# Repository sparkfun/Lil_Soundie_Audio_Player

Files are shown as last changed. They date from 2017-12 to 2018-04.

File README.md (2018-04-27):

SparkFun Little Soundie Audio Player
========================================

Little Soundie Audio Player

[*SparkFun Little Soundie (14006)*](https://www.sparkfun.com/products/14006)

The Little Soundie Audio Player is a breakout board for the VS1000D, an audio decoder capable of playing OGG and WAV type audio files. 
The Little Soundie makes adding sound effects to your project, prop, or costume easily with the built-in USB mass storage for your audio file and simple methods of triggering audio playback.  

Repository Contents
-------------------

* **/Firmware** - VLSI - VS1000D Firmware
* **/Hardware** - Eagle design files (.brd, .sch)
* **/Production** - Production panel files (.brd)
* **/Software** - An easy to use Arduino Template in case you want to hook up your Little Soundie to a Redboard or any board programmed with Arduino.

Documentation
--------------
* **[Hookup Guide](https://learn.sparkfun.com/tutorials/little-soundie-audio-player-hookup-guide)** - Basic hookup guide for the Little Soundie Audio Player.
* **[SparkFun Fritzing repo](https://github.com/sparkfun/Fritzing_Parts)** - Fritzing diagrams for SparkFun products. 

License Information
-------------------

This product is _**open source**_! 

Please review the LICENSE.md file for license information. 

If you have any questions or concerns on licensing, please contact techsupport@sparkfun.com.

Distributed as-is; no warranty is given.

- Your friends at SparkFun.

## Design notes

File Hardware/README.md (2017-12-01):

SparkFun <PRODUCT NAME> Design Files
=====================================

The .sch and .brd files hare are Eagle CAD schematic and PCB design files from SparkFun Electronics.
A freeware version of Eagle can be found [here](http://www.cadsoftusa.com/download-eagle/freeware/).

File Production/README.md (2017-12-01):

SparkFun <PRODUCT NAME> Production Files
=========================================

These are the production files SparkFun uses for printing PCBs.

License Information
-------------------
This product is open source! 

The hardware is released under [Creative Commons ShareAlike 4.0 International](https://creativecommons.org/licenses/by-sa/4.0/).

Please use, reuse, and modify these files as you see fit. Please maintain attribution to SparkFun Electronics and release anything derivative under the same license.

Distributed as-is; no warranty is given.

- Your friends at SparkFun.

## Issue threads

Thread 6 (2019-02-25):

Lil_Soundie_Audio_Player

sidh15, 2019-02-25:
I want to make Lil_Soundie_Audio_Player on a very small board size. Is it possible to make same kind of functionality on the possible smaller size with component?
If yes, what programming are required on the board, if I am buying components separately?                                                                                                                                                                                         I am thinking to place this IC LE25U40CMD from ON semiconductor, will it be compatible for small storage of audio size 150 KB.

bboyho, 2019-04-04:
Hi,

It should be possible to make the board smaller. You should check out the resources provided by the company that manufactures the IC for more information on how to program the IC. There is detailed information available on how to program the chip with the software via USB on the VS1000's product page => [ [http://www.vlsi.fi/en/products/vs1000.html](http://www.vlsi.fi/en/products/vs1000.html) ]. Our hookup guide states that we use the VSIDE software.

As far as the LE25U40CMD IC, this question seems to be out of scope of the product itself and not an issue related with the Lil' Soundie Audio Player. What I can say is that it looks like a SPI serial flash memory similar to the one that is on the Lil' Soundie Audio Player. However, I do not have as much experience with the chip and VS1000D. You should check out the resources linked for more information or check out the [VLSI support forums](http://www.vsdsp-forum.com/phpbb/).

Closed 2019-04-04.

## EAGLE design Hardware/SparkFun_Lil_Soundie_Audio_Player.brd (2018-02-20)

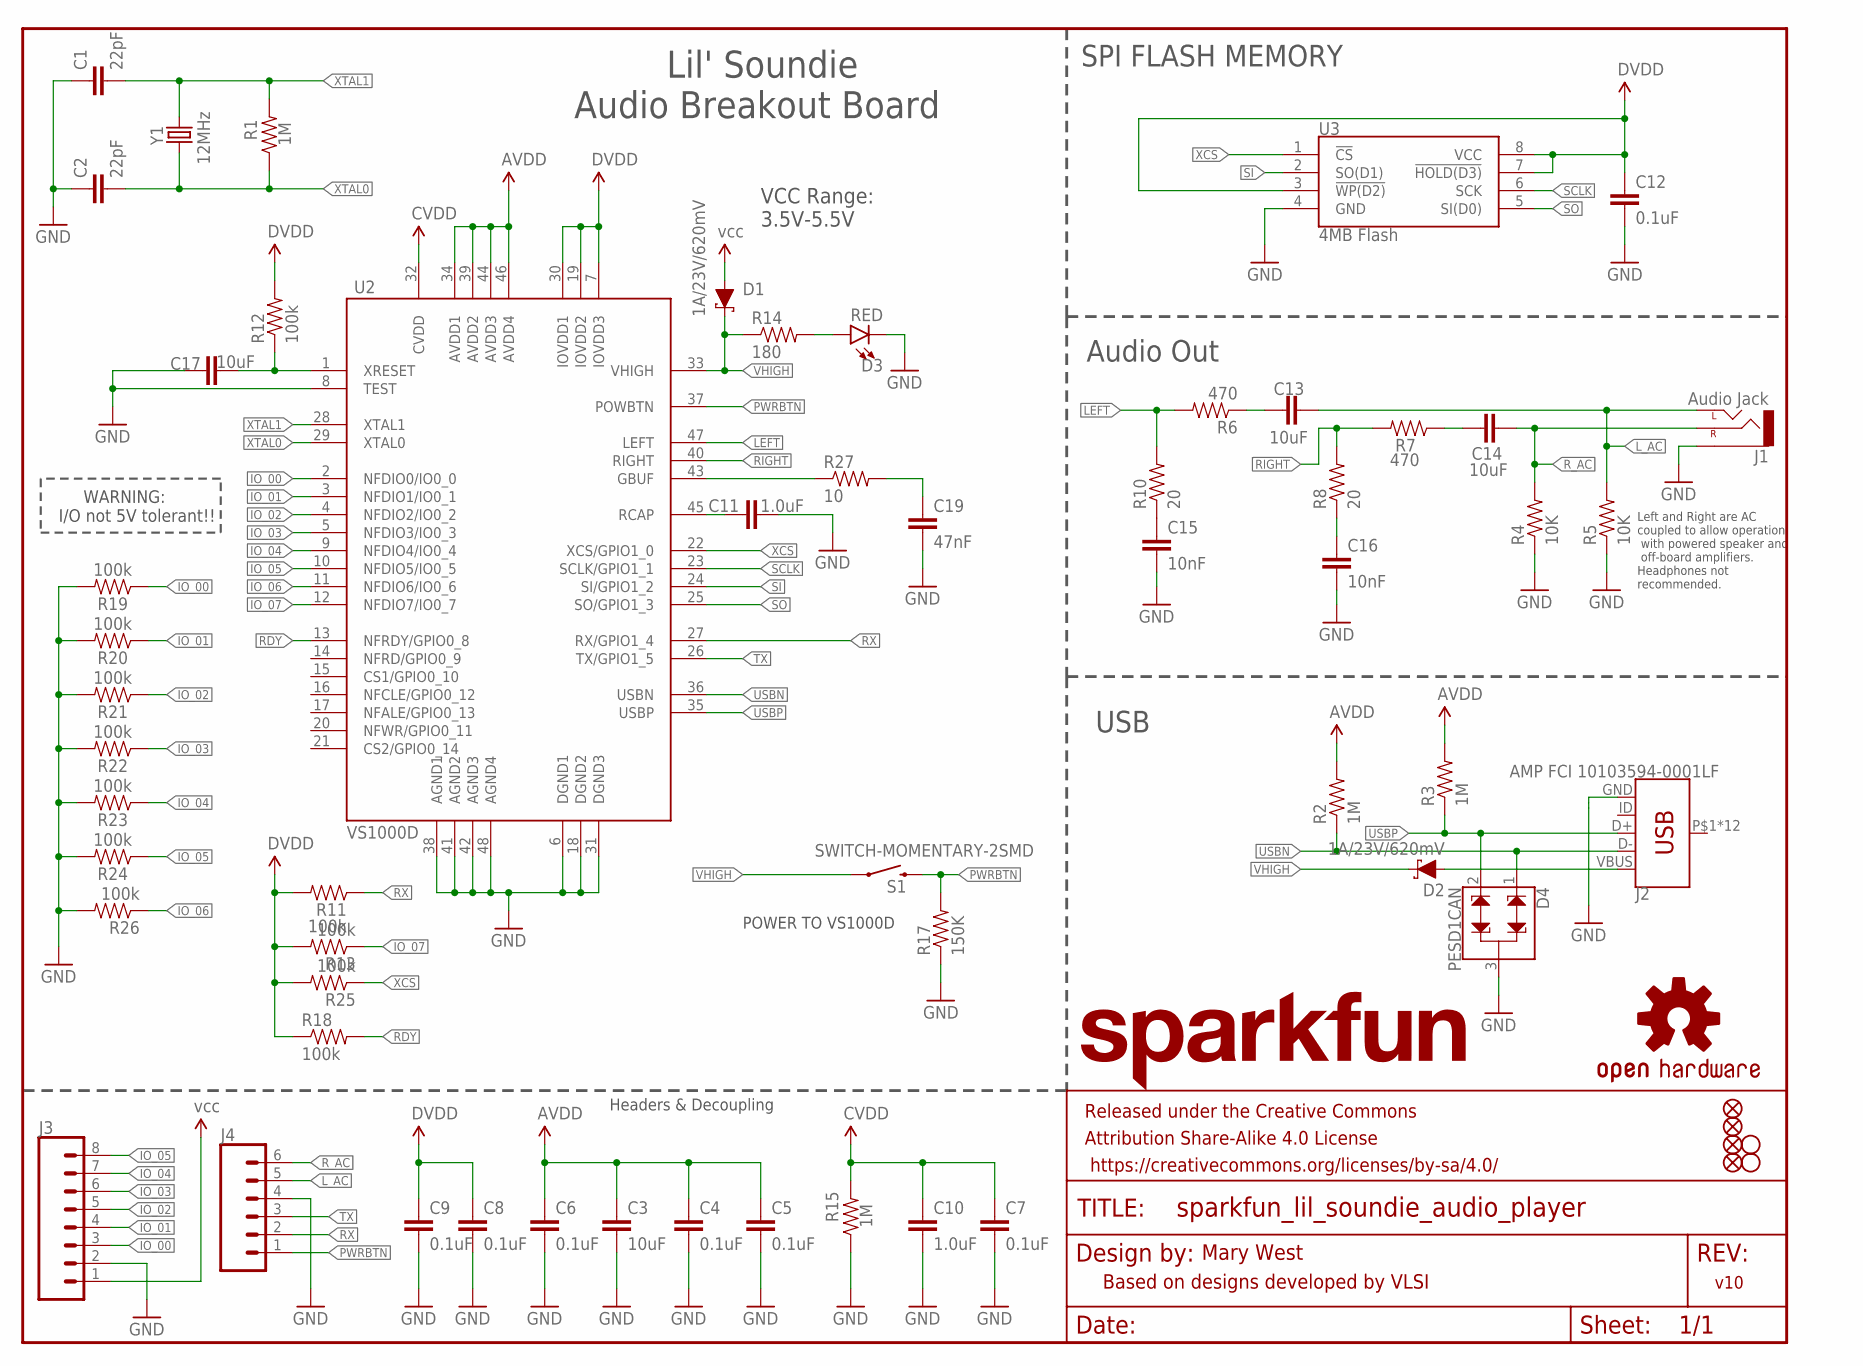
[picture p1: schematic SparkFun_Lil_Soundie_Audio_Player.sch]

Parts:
C1, C2: 22pF; 0603-CAP
C3, C13, C14, C17: 10uF; 0603-CAP
C4, C5, C6, C7, C8, C9, C12: 0.1uF; 0603-CAP
C10, C11: 1.0uF; 0603-CAP
C15, C16: 10nF; 0603-CAP
C19: 47nF; 0603-CAP
D1, D2: 1A/23V/620mV; SOD-323
D3: RED; LED-0603
D4: PESD1CAN; SOT23-3
FD1, FD2, FD3, FD4: FIDUCIALUFIDUCIAL; FIDUCIAL-MICRO
FRAME1: FRAME-LETTER; CREATIVE_COMMONS
H1, H4: STAND-OFFTIGHT; STAND-OFF-TIGHT
J1: Audio Jack; AUDIO-JACK-3.5MM-SMD
J2: AMP FCI 10103594-0001LF; USB-MICROB-PTH
J3: CONN_08"; 1X08
J4: CONN_06SILK_FEMALE_PTH; 1X06
LOGO1: OSHW-LOGOL; OSHW-LOGO-L
LOGO2: SFE_LOGO_NAME.1_INCH; SFE_LOGO_NAME_.1
R1, R2, R3, R15: 1M; 0603-RES
R4, R5: 10K; 0603-RES
R6, R7: 470; 0603-RES
R8, R10: 20; 0603-RES
R11, R12, R13, R18, R25, R26: 100k; 0603-RES
R14: 180; 0603-RES
R17: 150K; 0603-RES
R19, R20, R21, R22, R23, R24: 100k; 0603
R27: 10; 0603-RES
S1: SWITCH-MOMENTARY-2SMD; TACTILE-SWITCH-SMD
U2: VS1000D; LQFP-48
U3: 4MB Flash; SO08
Y1: 12MHz; CRYSTAL-SMD-5X3

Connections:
AVDD: C3.1, C4.1, C5.1, C6.1, R2.2, R3.2, U2.34 (AVDD1), U2.39 (AVDD2), U2.44 (AVDD3), U2.46 (AVDD4)
CVDD: C7.1, C10.1, R15.2, U2.32 (CVDD)
DVDD: C8.1, C9.1, C12.1, R11.2, R12.2, R13.2, R18.1, R25.2, U2.7 (IOVDD3), U2.19 (IOVDD2), U2.30 (IOVDD1), U3.3 (!WP(D2)), U3.7 (!HOLD(D3)), U3.8 (VCC)
GBUF: R27.1, U2.43 (GBUF)
GND: C1.1, C2.1, C3.2, C4.2, C5.2, C6.2, C7.2, C8.2, C9.2, C10.2, C11.2, C12.2, C15.2, C16.2, C17.1, C19.2, D3.C, D4.3, J1.SLEEVE, J2.GND, J3.2, J4.4, R4.1, R5.1, R15.1, R17.1, R19.2, R20.2, R21.2, R22.2, R23.2, R24.2, R26.2, U2.6 (DGND1), U2.8 (TEST), U2.18 (DGND2), U2.31 (DGND3), U2.38 (AGND1), U2.41 (AGND2), U2.42 (AGND3), U2.48 (AGND4), U3.4 (GND)
IO_00: J3.3, R19.1, U2.2 (NFDIO0/IO0_0)
IO_01: J3.4, R20.1, U2.3 (NFDIO1/IO0_1)
IO_02: J3.5, R21.1, U2.4 (NFDIO2/IO0_2)
IO_03: J3.6, R22.1, U2.5 (NFDIO3/IO0_3)
IO_04: J3.7, R23.1, U2.9 (NFDIO4/IO0_4)
IO_05: J3.8, R24.1, U2.10 (NFDIO5/IO0_5)
IO_06: R26.1, U2.11 (NFDIO6/IO0_6)
IO_07: R13.1, U2.12 (NFDIO7/IO0_7)
LEFT: R6.2, R10.2, U2.47 (LEFT)
L_AC: C13.2, J1.TIP (LEFT), J4.5, R5.2
unnamed: C19.1, R27.2
unnamed: C13.1, R6.1
unnamed: C15.1, R10.1
unnamed: C11.1, U2.45 (RCAP)
unnamed: C17.2, R12.1, U2.1 (XRESET)
unnamed: D2.A, J2.VBUS
unnamed: C14.1, R7.1
unnamed: D3.A, R14.2
unnamed: C16.1, R8.1
PWRBTN: J4.1, R17.2, S1.3 (2), U2.37 (POWBTN)
RDY: R18.2, U2.13 (NFRDY/GPIO0_8)
RIGHT: R7.2, R8.2, U2.40 (RIGHT)
RX: J4.2, U2.27 (RX/GPIO1_4)
R_AC: C14.2, J1.RING (RIGHT), J4.6, R4.2
SCLK: U2.23 (SCLK/GPIO1_1), U3.6 (SCK)
SI: U2.24 (SI/GPIO1_2), U3.2 (SO(D1))
SO: U2.25 (SO/GPIO1_3), U3.5 (SI(D0))
TX: J4.3, U2.26 (TX/GPIO1_5)
USBN: D4.1, J2.D-, R2.1, U2.36 (USBN)
USBP: D4.2, J2.D+, R3.1, U2.35 (USBP)
VCC: D1.A, J3.1
VHIGH: D1.C, D2.C, R14.1, S1.1, U2.33 (VHIGH)
XCS: R25.1, U2.22 (XCS/GPIO1_0), U3.1 (!CS)
XTAL0: C2.2, R1.1, U2.29 (XTAL0), Y1.1
XTAL1: C1.2, R1.2, U2.28 (XTAL1), Y1.3 (2)

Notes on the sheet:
Mary West
v10
VCC Range: 3.5V-5.5V
SPI FLASH MEMORY
Headers & Decoupling
POWER TO VS1000D
Left and Right are AC coupled to allow operation with powered speaker and off-board amplifiers. Headphones not recommended.
Based on designs developed by VLSI
WARNING: I/O not 5V tolerant!!
USB
Audio Out
Lil' Soundie Audio Breakout Board

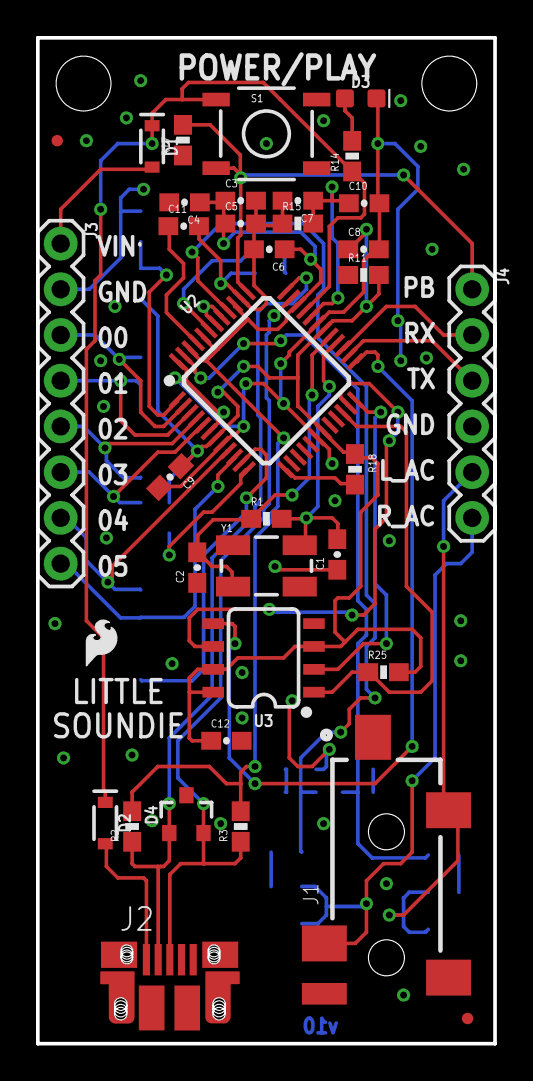
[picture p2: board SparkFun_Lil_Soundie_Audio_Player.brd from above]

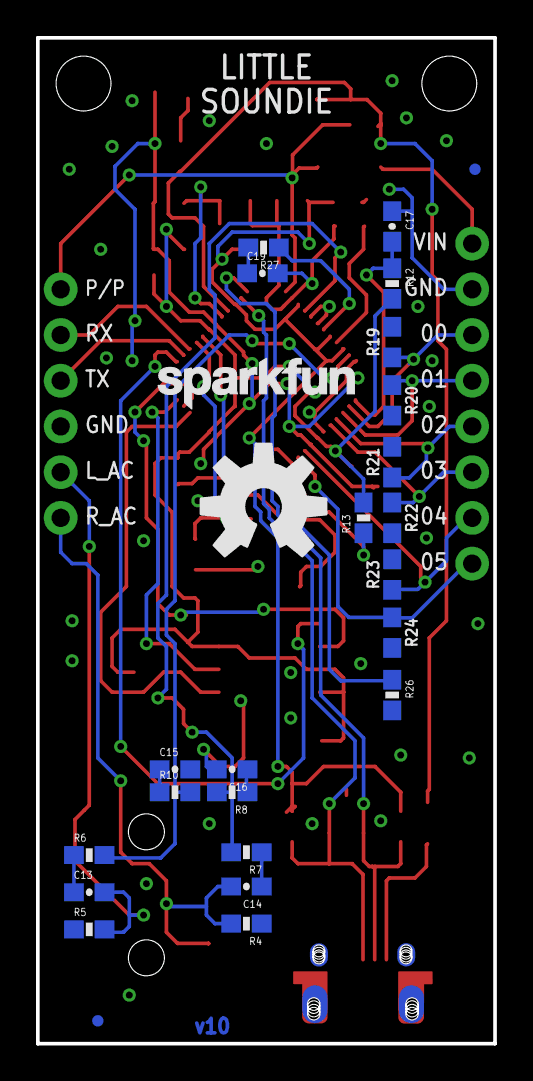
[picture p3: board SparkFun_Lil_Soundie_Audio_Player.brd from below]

Board: 2 copper layers, 25.4 x 55.9 mm, 65 parts (26 on the bottom side), 40 nets.

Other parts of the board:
U$1: SFE_LOGO_FLAME_.1

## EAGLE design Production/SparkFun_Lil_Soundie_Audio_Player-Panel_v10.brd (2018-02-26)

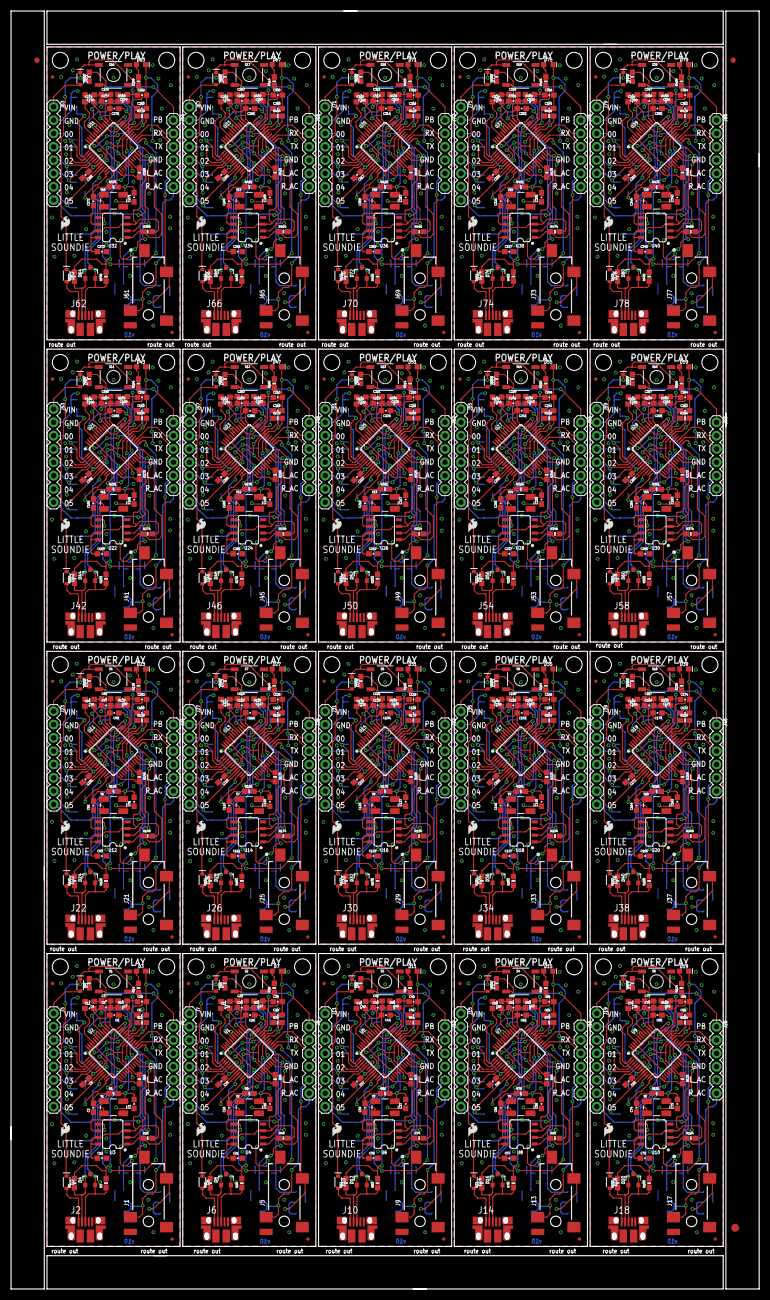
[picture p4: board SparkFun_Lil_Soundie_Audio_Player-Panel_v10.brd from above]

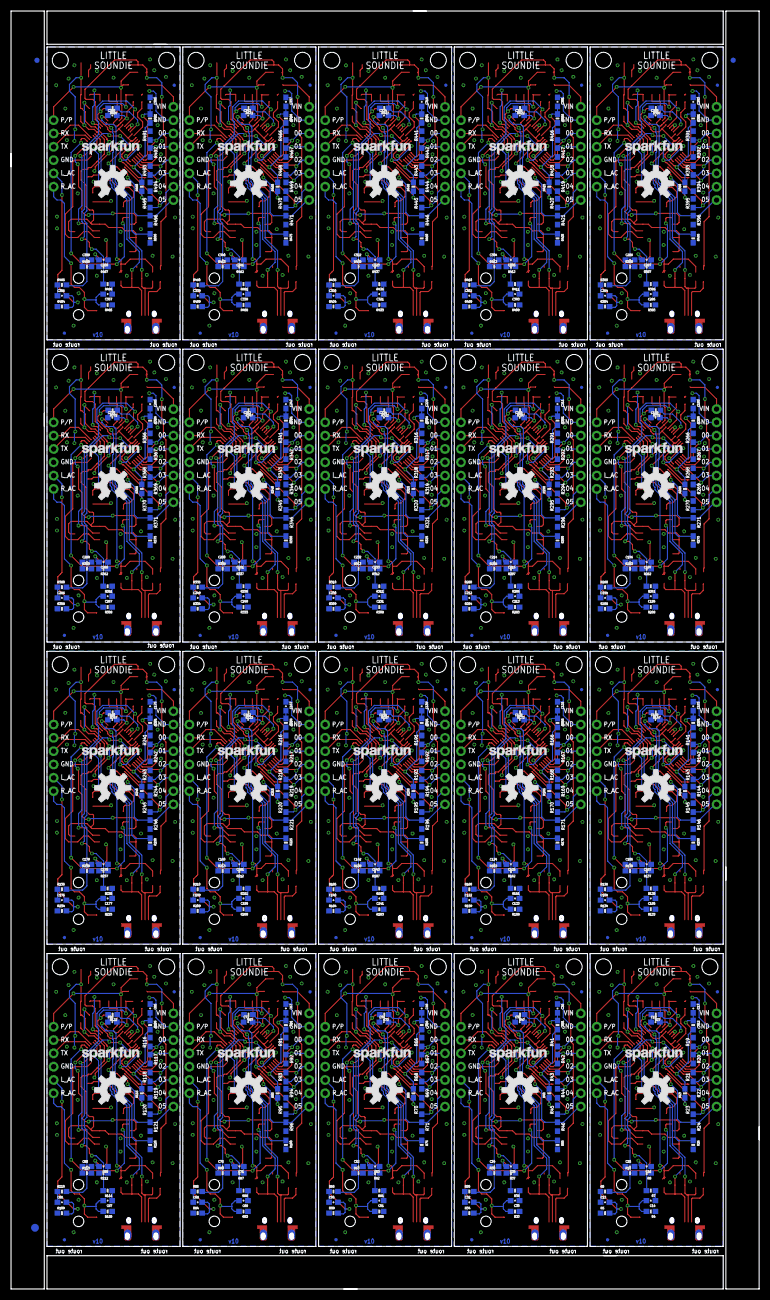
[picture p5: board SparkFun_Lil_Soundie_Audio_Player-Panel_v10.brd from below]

Board: 2 copper layers, 142.7 x 243.8 mm, 1286 parts (523 on the bottom side), 800 nets.

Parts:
C1, C2, C18, C20, C37, C38, C55, C56, C73, C74, C91, C92, C109, C110, C127, C128, C145, C146, C163, C164, C181, C182, C199, C200, C217, C218, C235, C236, C253, C254, C271, C272, C289, C290, C307, C308, C325, C326, C343, C344: 22pF; 0603-CAP
C3, C13, C14, C17, C23, C31, C32, C33, C41, C49, C50, C51, C59, C67, C68, C69, C77, C85, C86, C87, C95, C103, C104, C105, C113, C121, C122, C123, C131, C139, C140, C141, C149, C157, C158, C159, C167, C175, C176, C177, C185, C193, C194, C195, C203, C211, C212, C213, C221, C229, C230, C231, C239, C247, C248, C249, C257, C265, C266, C267, C275, C283, C284, C285, C293, C301, C302, C303, C311, C319, C320, C321, C329, C337, C338, C339, C347, C355, C356, C357: 10uF; 0603-CAP
C4, C5, C6, C7, C8, C9, C12, C21, C24, C25, C26, C27, C28, C29, C39, C42, C43, C44, C45, C46, C47, C57, C60, C61, C62, C63, C64, C65, C75, C78, C79, C80, C81, C82, C83, C93, C96, C97, C98, C99, C100, C101, C111, C114, C115, C116, C117, C118, C119, C129, C132, C133, C134, C135, C136, C137, C147, C150, C151, C152, C153, C154, C155, C165, C168, C169, C170, C171, C172, C173, C183, C186, C187, C188, C189, C190, C191, C201, C204, C205, C206, C207, C208, C209, C219, C222, C223, C224, C225, C226, C227, C237, C240, C241, C242, C243, C244, C245, C255, C258, C259, C260, C261, C262, C263, C273, C276, C277, C278, C279, C280, C281, C291, C294, C295, C296, C297, C298, C299, C309, C312, C313, C314, C315, C316, C317, C327, C330, C331, C332, C333, C334, C335, C345, C348, C349, C350, C351, C352, C353: 0.1uF; 0603-CAP
C10, C11, C22, C30, C40, C48, C58, C66, C76, C84, C94, C102, C112, C120, C130, C138, C148, C156, C166, C174, C184, C192, C202, C210, C220, C228, C238, C246, C256, C264, C274, C282, C292, C300, C310, C318, C328, C336, C346, C354: 1.0uF; 0603-CAP
C15, C16, C34, C35, C52, C53, C70, C71, C88, C89, C106, C107, C124, C125, C142, C143, C160, C161, C178, C179, C196, C197, C214, C215, C232, C233, C250, C251, C268, C269, C286, C287, C304, C305, C322, C323, C340, C341, C358, C359: 10nF; 0603-CAP
C19, C36, C54, C72, C90, C108, C126, C144, C162, C180, C198, C216, C234, C252, C270, C288, C306, C324, C342, C360: 47nF; 0603-CAP
D1, D2, D5, D6, D9, D10, D13, D14, D17, D18, D21, D22, D25, D26, D29, D30, D33, D34, D37, D38, D41, D42, D45, D46, D49, D50, D53, D54, D57, D58, D61, D62, D65, D66, D69, D70, D73, D74, D77, D78: 1A/23V/620mV; SOD-323
D3, D7, D11, D15, D19, D23, D27, D31, D35, D39, D43, D47, D51, D55, D59, D63, D67, D71, D75, D79: RED; LED-0603
D4, D8, D12, D16, D20, D24, D28, D32, D36, D40, D44, D48, D52, D56, D60, D64, D68, D72, D76, D80: PESD1CAN; SOT23-3
E$1, E$2, E$6, E$7: FIDUCIAL-1X2
E$3, E$4: FIDUCIAL-1.5X3
FD1, FD2, FD3, FD4, FD5, FD6, FD7, FD8, FD9, FD10, FD11, FD12, FD13, FD14, FD15, FD16, FD17, FD18, FD19, FD20, FD21, FD22, FD23, FD24, FD25, FD26, FD27, FD28, FD29, FD30, FD31, FD32, FD33, FD34, FD35, FD36, FD37, FD38, FD39, FD40, FD41, FD42, FD43, FD44, FD45, FD46, FD47, FD48, FD49, FD50, FD51, FD52, FD53, FD54, FD55, FD56, FD57, FD58, FD59, FD60, FD61, FD62, FD63, FD64, FD65, FD66, FD67, FD68, FD69, FD70, FD71, FD72, FD73, FD74, FD75, FD76, FD77, FD78, FD79, FD80: FIDUCIALUFIDUCIAL; FIDUCIAL-MICRO
H1, H2, H3, H4, H5, H6, H7, H8, H9, H10, H11, H12, H13, H14, H15, H16, H17, H18, H19, H20, H21, H22, H23, H24, H25, H26, H27, H28, H29, H30, H31, H32, H33, H34, H35, H36, H37, H38, H39, H40: STAND-OFFTIGHT; STAND-OFF-TIGHT
J1, J5, J9, J13, J17, J21, J25, J29, J33, J37, J41, J45, J49, J53, J57, J61, J65, J69, J73, J77: Audio Jack; AUDIO-JACK-3.5MM-SMD
J2, J6, J10, J14, J18, J22, J26, J30, J34, J38, J42, J46, J50, J54, J58, J62, J66, J70, J74, J78: AMP FCI 10103594-0001LF; USB-MICROB-PTH
J3, J7, J11, J15, J19, J23, J27, J31, J35, J39, J43, J47, J51, J55, J59, J63, J67, J71, J75, J79: 1X08
J4, J8, J12, J16, J20, J24, J28, J32, J36, J40, J44, J48, J52, J56, J60, J64, J68, J72, J76, J80: 1X06
LOGO1, LOGO3, LOGO5, LOGO7, LOGO9, LOGO11, LOGO13, LOGO15, LOGO17, LOGO19, LOGO21, LOGO23, LOGO25, LOGO27, LOGO29, LOGO31, LOGO33, LOGO35, LOGO37, LOGO39: OSHW-LOGOL; OSHW-LOGO-L
LOGO2, LOGO4, LOGO6, LOGO8, LOGO10, LOGO12, LOGO14, LOGO16, LOGO18, LOGO20, LOGO22, LOGO24, LOGO26, LOGO28, LOGO30, LOGO32, LOGO34, LOGO36, LOGO38, LOGO40: SFE_LOGO_NAME.1_INCH; SFE_LOGO_NAME_.1
R1, R2, R3, R9, R15, R16, R28, R30, R51, R52, R53, R55, R76, R77, R78, R80, R101, R102, R103, R105, R126, R127, R128, R130, R151, R152, R153, R155, R176, R177, R178, R180, R201, R202, R203, R205, R226, R227, R228, R230, R251, R252, R253, R255, R276, R277, R278, R280, R301, R302, R303, R305, R326, R327, R328, R330, R351, R352, R353, R355, R376, R377, R378, R380, R401, R402, R403, R405, R426, R427, R428, R430, R451, R452, R453, R455, R476, R477, R478, R480: 1M; 0603-RES
R4, R5, R33, R34, R58, R59, R83, R84, R108, R109, R133, R134, R158, R159, R183, R184, R208, R209, R233, R234, R258, R259, R283, R284, R308, R309, R333, R334, R358, R359, R383, R384, R408, R409, R433, R434, R458, R459, R483, R484: 10K; 0603-RES
R6, R7, R35, R36, R60, R61, R85, R86, R110, R111, R135, R136, R160, R161, R185, R186, R210, R211, R235, R236, R260, R261, R285, R286, R310, R311, R335, R336, R360, R361, R385, R386, R410, R411, R435, R436, R460, R461, R485, R486: 470; 0603-RES
R8, R10, R37, R38, R62, R63, R87, R88, R112, R113, R137, R138, R162, R163, R187, R188, R212, R213, R237, R238, R262, R263, R287, R288, R312, R313, R337, R338, R362, R363, R387, R388, R412, R413, R437, R438, R462, R463, R487, R488: 20; 0603-RES
R11, R12, R13, R18, R25, R26, R29, R31, R40, R48, R49, R50, R54, R56, R65, R73, R74, R75, R79, R81, R90, R98, R99, R100, R104, R106, R115, R123, R124, R125, R129, R131, R140, R148, R149, R150, R154, R156, R165, R173, R174, R175, R179, R181, R190, R198, R199, R200, R204, R206, R215, R223, R224, R225, R229, R231, R240, R248, R249, R250, R254, R256, R265, R273, R274, R275, R279, R281, R290, R298, R299, R300, R304, R306, R315, R323, R324, R325, R329, R331, R340, R348, R349, R350, R354, R356, R365, R373, R374, R375, R379, R381, R390, R398, R399, R400, R404, R406, R415, R423, R424, R425, R429, R431, R440, R448, R449, R450, R454, R456, R465, R473, R474, R475, R479, R481, R490, R498, R499, R500: 100k; 0603-RES
R14, R39, R64, R89, R114, R139, R164, R189, R214, R239, R264, R289, R314, R339, R364, R389, R414, R439, R464, R489: 180; 0603-RES
R17, R32, R57, R82, R107, R132, R157, R182, R207, R232, R257, R282, R307, R332, R357, R382, R407, R432, R457, R482: 150K; 0603-RES
R19, R20, R21, R22, R23, R24, R41, R42, R43, R44, R45, R46, R66, R67, R68, R69, R70, R71, R91, R92, R93, R94, R95, R96, R116, R117, R118, R119, R120, R121, R141, R142, R143, R144, R145, R146, R166, R167, R168, R169, R170, R171, R191, R192, R193, R194, R195, R196, R216, R217, R218, R219, R220, R221, R241, R242, R243, R244, R245, R246, R266, R267, R268, R269, R270, R271, R291, R292, R293, R294, R295, R296, R316, R317, R318, R319, R320, R321, R341, R342, R343, R344, R345, R346, R366, R367, R368, R369, R370, R371, R391, R392, R393, R394, R395, R396, R416, R417, R418, R419, R420, R421, R441, R442, R443, R444, R445, R446, R466, R467, R468, R469, R470, R471, R491, R492, R493, R494, R495, R496: 100k; 0603
R27, R47, R72, R97, R122, R147, R172, R197, R222, R247, R272, R297, R322, R347, R372, R397, R422, R447, R472, R497: 10; 0603-RES
S1, S2, S3, S4, S5, S6, S7, S8, S9, S10, S11, S12, S13, S14, S15, S16, S17, S18, S19, S20: SWITCH-MOMENTARY-2SMD; TACTILE-SWITCH-SMD
U1, U2, U5, U7, U9, U11, U13, U15, U17, U19, U21, U23, U25, U27, U29, U31, U33, U35, U37, U39: VS1000D; LQFP-48
U3, U4, U6, U8, U10, U12, U14, U16, U18, U20, U22, U24, U26, U28, U30, U32, U34, U36, U38, U40: 4MB Flash; SO08
U$1, U$2, U$3, U$4, U$5, U$6, U$7, U$8, U$9, U$10, U$11, U$12, U$13, U$14, U$15, U$16, U$17, U$18, U$19, U$20: SFE_LOGO_FLAME_.1
Y1, Y2, Y3, Y4, Y5, Y6, Y7, Y8, Y9, Y10, Y11, Y12, Y13, Y14, Y15, Y16, Y17, Y18, Y19, Y20: 12MHz; CRYSTAL-SMD-5X3

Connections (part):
AVDD: C3.1, C4.1, C5.1, C6.1, R2.2, R3.2, U2.34, U2.39, U2.44, U2.46
AVDD1: C23.1, C24.1, C25.1, C26.1, R16.2, R28.2, U1.34, U1.39, U1.44, U1.46
AVDD2: C41.1, C42.1, C43.1, C44.1, R52.2, R53.2, U5.34, U5.39, U5.44, U5.46
AVDD3: C59.1, C60.1, C61.1, C62.1, R77.2, R78.2, U7.34, U7.39, U7.44, U7.46
AVDD4: C77.1, C78.1, C79.1, C80.1, R102.2, R103.2, U9.34, U9.39, U9.44, U9.46
AVDD5: C95.1, C96.1, C97.1, C98.1, R127.2, R128.2, U11.34, U11.39, U11.44, U11.46
AVDD6: C113.1, C114.1, C115.1, C116.1, R152.2, R153.2, U13.34, U13.39, U13.44, U13.46
AVDD7: C131.1, C132.1, C133.1, C134.1, R177.2, R178.2, U15.34, U15.39, U15.44, U15.46
AVDD8: C149.1, C150.1, C151.1, C152.1, R202.2, R203.2, U17.34, U17.39, U17.44, U17.46
AVDD9: C167.1, C168.1, C169.1, C170.1, R227.2, R228.2, U19.34, U19.39, U19.44, U19.46
AVDD10: C185.1, C186.1, C187.1, C188.1, R252.2, R253.2, U21.34, U21.39, U21.44, U21.46
AVDD11: C203.1, C204.1, C205.1, C206.1, R277.2, R278.2, U23.34, U23.39, U23.44, U23.46
AVDD12: C221.1, C222.1, C223.1, C224.1, R302.2, R303.2, U25.34, U25.39, U25.44, U25.46
AVDD13: C239.1, C240.1, C241.1, C242.1, R327.2, R328.2, U27.34, U27.39, U27.44, U27.46
AVDD14: C257.1, C258.1, C259.1, C260.1, R352.2, R353.2, U29.34, U29.39, U29.44, U29.46
AVDD15: C275.1, C276.1, C277.1, C278.1, R377.2, R378.2, U31.34, U31.39, U31.44, U31.46
AVDD16: C293.1, C294.1, C295.1, C296.1, R402.2, R403.2, U33.34, U33.39, U33.44, U33.46
AVDD17: C311.1, C312.1, C313.1, C314.1, R427.2, R428.2, U35.34, U35.39, U35.44, U35.46
AVDD18: C329.1, C330.1, C331.1, C332.1, R452.2, R453.2, U37.34, U37.39, U37.44, U37.46
AVDD19: C347.1, C348.1, C349.1, C350.1, R477.2, R478.2, U39.34, U39.39, U39.44, U39.46
CVDD: C7.1, C10.1, R15.2, U2.32
CVDD1: C27.1, C30.1, R30.2, U1.32
CVDD2: C45.1, C48.1, R55.2, U5.32
CVDD3: C63.1, C66.1, R80.2, U7.32
CVDD4: C81.1, C84.1, R105.2, U9.32
CVDD5: C99.1, C102.1, R130.2, U11.32
CVDD6: C117.1, C120.1, R155.2, U13.32
CVDD7: C135.1, C138.1, R180.2, U15.32
CVDD8: C153.1, C156.1, R205.2, U17.32
CVDD9: C171.1, C174.1, R230.2, U19.32
CVDD10: C189.1, C192.1, R255.2, U21.32
CVDD11: C207.1, C210.1, R280.2, U23.32
CVDD12: C225.1, C228.1, R305.2, U25.32
CVDD13: C243.1, C246.1, R330.2, U27.32
CVDD14: C261.1, C264.1, R355.2, U29.32
CVDD15: C279.1, C282.1, R380.2, U31.32
CVDD16: C297.1, C300.1, R405.2, U33.32
CVDD17: C315.1, C318.1, R430.2, U35.32
CVDD18: C333.1, C336.1, R455.2, U37.32
CVDD19: C351.1, C354.1, R480.2, U39.32
DVDD: C8.1, C9.1, C12.1, R11.2, R12.2, R13.2, R18.1, R25.2, U2.7, U2.19, U2.30, U3.3, U3.7, U3.8
DVDD1: C21.1, C28.1, C29.1, R29.2, R31.2, R40.2, R48.1, R49.2, U1.7, U1.19, U1.30, U4.3, U4.7, U4.8
DVDD2: C39.1, C46.1, C47.1, R54.2, R56.2, R65.2, R73.1, R74.2, U5.7, U5.19, U5.30, U6.3, U6.7, U6.8
DVDD3: C57.1, C64.1, C65.1, R79.2, R81.2, R90.2, R98.1, R99.2, U7.7, U7.19, U7.30, U8.3, U8.7, U8.8
DVDD4: C75.1, C82.1, C83.1, R104.2, R106.2, R115.2, R123.1, R124.2, U9.7, U9.19, U9.30, U10.3, U10.7, U10.8
DVDD5: C93.1, C100.1, C101.1, R129.2, R131.2, R140.2, R148.1, R149.2, U11.7, U11.19, U11.30, U12.3, U12.7, U12.8
DVDD6: C111.1, C118.1, C119.1, R154.2, R156.2, R165.2, R173.1, R174.2, U13.7, U13.19, U13.30, U14.3, U14.7, U14.8
DVDD7: C129.1, C136.1, C137.1, R179.2, R181.2, R190.2, R198.1, R199.2, U15.7, U15.19, U15.30, U16.3, U16.7, U16.8
DVDD8: C147.1, C154.1, C155.1, R204.2, R206.2, R215.2, R223.1, R224.2, U17.7, U17.19, U17.30, U18.3, U18.7, U18.8
DVDD9: C165.1, C172.1, C173.1, R229.2, R231.2, R240.2, R248.1, R249.2, U19.7, U19.19, U19.30, U20.3, U20.7, U20.8
DVDD10: C183.1, C190.1, C191.1, R254.2, R256.2, R265.2, R273.1, R274.2, U21.7, U21.19, U21.30, U22.3, U22.7, U22.8
DVDD11: C201.1, C208.1, C209.1, R279.2, R281.2, R290.2, R298.1, R299.2, U23.7, U23.19, U23.30, U24.3, U24.7, U24.8
DVDD12: C219.1, C226.1, C227.1, R304.2, R306.2, R315.2, R323.1, R324.2, U25.7, U25.19, U25.30, U26.3, U26.7, U26.8
DVDD13: C237.1, C244.1, C245.1, R329.2, R331.2, R340.2, R348.1, R349.2, U27.7, U27.19, U27.30, U28.3, U28.7, U28.8
DVDD14: C255.1, C262.1, C263.1, R354.2, R356.2, R365.2, R373.1, R374.2, U29.7, U29.19, U29.30, U30.3, U30.7, U30.8
DVDD15: C273.1, C280.1, C281.1, R379.2, R381.2, R390.2, R398.1, R399.2, U31.7, U31.19, U31.30, U32.3, U32.7, U32.8
DVDD16: C291.1, C298.1, C299.1, R404.2, R406.2, R415.2, R423.1, R424.2, U33.7, U33.19, U33.30, U34.3, U34.7, U34.8
DVDD17: C309.1, C316.1, C317.1, R429.2, R431.2, R440.2, R448.1, R449.2, U35.7, U35.19, U35.30, U36.3, U36.7, U36.8
DVDD18: C327.1, C334.1, C335.1, R454.2, R456.2, R465.2, R473.1, R474.2, U37.7, U37.19, U37.30, U38.3, U38.7, U38.8
DVDD19: C345.1, C352.1, C353.1, R479.2, R481.2, R490.2, R498.1, R499.2, U39.7, U39.19, U39.30, U40.3, U40.7, U40.8
GBUF: R27.1, U2.43
GBUF1: R47.1, U1.43
GBUF2: R72.1, U5.43
GBUF3: R97.1, U7.43
GBUF4: R122.1, U9.43
GBUF5: R147.1, U11.43
GBUF6: R172.1, U13.43
GBUF7: R197.1, U15.43
GBUF8: R222.1, U17.43
GBUF9: R247.1, U19.43
GBUF10: R272.1, U21.43
GBUF11: R297.1, U23.43
GBUF12: R322.1, U25.43
GBUF13: R347.1, U27.43
GBUF14: R372.1, U29.43
GBUF15: R397.1, U31.43
GBUF16: R422.1, U33.43
GBUF17: R447.1, U35.43
GBUF18: R472.1, U37.43
GBUF19: R497.1, U39.43
GND: C1.1, C2.1, C3.2, C4.2, C5.2, C6.2, C7.2, C8.2, C9.2, C10.2, C11.2, C12.2, C15.2, C16.2, C17.1, C19.2, D3.C, D4.3, J1.SLEEVE, J2.GND, J3.2, J4.4, R4.1, R5.1, R15.1, R17.1, R19.2, R20.2, R21.2, R22.2, R23.2, R24.2, R26.2, U2.6, U2.8, U2.18, U2.31, U2.38, U2.41, U2.42, U2.48, U3.4
GND1: C18.1, C20.1, C21.2, C22.2, C23.2, C24.2, C25.2, C26.2, C27.2, C28.2, C29.2, C30.2, C31.1, C34.2, C35.2, C36.2, D7.C, D8.3, J5.SLEEVE, J6.GND, J7.2, J8.4, R30.1, R32.1, R33.1, R34.1, R41.2, R42.2, R43.2, R44.2, R45.2, R46.2, R50.2, U1.6, U1.8, U1.18, U1.31, U1.38, U1.41, U1.42, U1.48, U4.4
GND2: C37.1, C38.1, C39.2, C40.2, C41.2, C42.2, C43.2, C44.2, C45.2, C46.2, C47.2, C48.2, C49.1, C52.2, C53.2, C54.2, D11.C, D12.3, J9.SLEEVE, J10.GND, J11.2, J12.4, R55.1, R57.1, R58.1, R59.1, R66.2, R67.2, R68.2, R69.2, R70.2, R71.2, R75.2, U5.6, U5.8, U5.18, U5.31, U5.38, U5.41, U5.42, U5.48, U6.4
GND3: C55.1, C56.1, C57.2, C58.2, C59.2, C60.2, C61.2, C62.2, C63.2, C64.2, C65.2, C66.2, C67.1, C70.2, C71.2, C72.2, D15.C, D16.3, J13.SLEEVE, J14.GND, J15.2, J16.4, R80.1, R82.1, R83.1, R84.1, R91.2, R92.2, R93.2, R94.2, R95.2, R96.2, R100.2, U7.6, U7.8, U7.18, U7.31, U7.38, U7.41, U7.42, U7.48, U8.4
GND4: C73.1, C74.1, C75.2, C76.2, C77.2, C78.2, C79.2, C80.2, C81.2, C82.2, C83.2, C84.2, C85.1, C88.2, C89.2, C90.2, D19.C, D20.3, J17.SLEEVE, J18.GND, J19.2, J20.4, R105.1, R107.1, R108.1, R109.1, R116.2, R117.2, R118.2, R119.2, R120.2, R121.2, R125.2, U9.6, U9.8, U9.18, U9.31, U9.38, U9.41, U9.42, U9.48, U10.4
GND5: C91.1, C92.1, C93.2, C94.2, C95.2, C96.2, C97.2, C98.2, C99.2, C100.2, C101.2, C102.2, C103.1, C106.2, C107.2, C108.2, D23.C, D24.3, J21.SLEEVE, J22.GND, J23.2, J24.4, R130.1, R132.1, R133.1, R134.1, R141.2, R142.2, R143.2, R144.2, R145.2, R146.2, R150.2, U11.6, U11.8, U11.18, U11.31, U11.38, U11.41, U11.42, U11.48, U12.4
GND6: C109.1, C110.1, C111.2, C112.2, C113.2, C114.2, C115.2, C116.2, C117.2, C118.2, C119.2, C120.2, C121.1, C124.2, C125.2, C126.2, D27.C, D28.3, J25.SLEEVE, J26.GND, J27.2, J28.4, R155.1, R157.1, R158.1, R159.1, R166.2, R167.2, R168.2, R169.2, R170.2, R171.2, R175.2, U13.6, U13.8, U13.18, U13.31, U13.38, U13.41, U13.42, U13.48, U14.4
GND7: C127.1, C128.1, C129.2, C130.2, C131.2, C132.2, C133.2, C134.2, C135.2, C136.2, C137.2, C138.2, C139.1, C142.2, C143.2, C144.2, D31.C, D32.3, J29.SLEEVE, J30.GND, J31.2, J32.4, R180.1, R182.1, R183.1, R184.1, R191.2, R192.2, R193.2, R194.2, R195.2, R196.2, R200.2, U15.6, U15.8, U15.18, U15.31, U15.38, U15.41, U15.42, U15.48, U16.4
GND8: C145.1, C146.1, C147.2, C148.2, C149.2, C150.2, C151.2, C152.2, C153.2, C154.2, C155.2, C156.2, C157.1, C160.2, C161.2, C162.2, D35.C, D36.3, J33.SLEEVE, J34.GND, J35.2, J36.4, R205.1, R207.1, R208.1, R209.1, R216.2, R217.2, R218.2, R219.2, R220.2, R221.2, R225.2, U17.6, U17.8, U17.18, U17.31, U17.38, U17.41, U17.42, U17.48, U18.4
GND9: C163.1, C164.1, C165.2, C166.2, C167.2, C168.2, C169.2, C170.2, C171.2, C172.2, C173.2, C174.2, C175.1, C178.2, C179.2, C180.2, D39.C, D40.3, J37.SLEEVE, J38.GND, J39.2, J40.4, R230.1, R232.1, R233.1, R234.1, R241.2, R242.2, R243.2, R244.2, R245.2, R246.2, R250.2, U19.6, U19.8, U19.18, U19.31, U19.38, U19.41, U19.42, U19.48, U20.4
GND10: C181.1, C182.1, C183.2, C184.2, C185.2, C186.2, C187.2, C188.2, C189.2, C190.2, C191.2, C192.2, C193.1, C196.2, C197.2, C198.2, D43.C, D44.3, J41.SLEEVE, J42.GND, J43.2, J44.4, R255.1, R257.1, R258.1, R259.1, R266.2, R267.2, R268.2, R269.2, R270.2, R271.2, R275.2, U21.6, U21.8, U21.18, U21.31, U21.38, U21.41, U21.42, U21.48, U22.4
GND11: C199.1, C200.1, C201.2, C202.2, C203.2, C204.2, C205.2, C206.2, C207.2, C208.2, C209.2, C210.2, C211.1, C214.2, C215.2, C216.2, D47.C, D48.3, J45.SLEEVE, J46.GND, J47.2, J48.4, R280.1, R282.1, R283.1, R284.1, R291.2, R292.2, R293.2, R294.2, R295.2, R296.2, R300.2, U23.6, U23.8, U23.18, U23.31, U23.38, U23.41, U23.42, U23.48, U24.4
GND12: C217.1, C218.1, C219.2, C220.2, C221.2, C222.2, C223.2, C224.2, C225.2, C226.2, C227.2, C228.2, C229.1, C232.2, C233.2, C234.2, D51.C, D52.3, J49.SLEEVE, J50.GND, J51.2, J52.4, R305.1, R307.1, R308.1, R309.1, R316.2, R317.2, R318.2, R319.2, R320.2, R321.2, R325.2, U25.6, U25.8, U25.18, U25.31, U25.38, U25.41, U25.42, U25.48, U26.4
GND13: C235.1, C236.1, C237.2, C238.2, C239.2, C240.2, C241.2, C242.2, C243.2, C244.2, C245.2, C246.2, C247.1, C250.2, C251.2, C252.2, D55.C, D56.3, J53.SLEEVE, J54.GND, J55.2, J56.4, R330.1, R332.1, R333.1, R334.1, R341.2, R342.2, R343.2, R344.2, R345.2, R346.2, R350.2, U27.6, U27.8, U27.18, U27.31, U27.38, U27.41, U27.42, U27.48, U28.4
GND14: C253.1, C254.1, C255.2, C256.2, C257.2, C258.2, C259.2, C260.2, C261.2, C262.2, C263.2, C264.2, C265.1, C268.2, C269.2, C270.2, D59.C, D60.3, J57.SLEEVE, J58.GND, J59.2, J60.4, R355.1, R357.1, R358.1, R359.1, R366.2, R367.2, R368.2, R369.2, R370.2, R371.2, R375.2, U29.6, U29.8, U29.18, U29.31, U29.38, U29.41, U29.42, U29.48, U30.4
GND15: C271.1, C272.1, C273.2, C274.2, C275.2, C276.2, C277.2, C278.2, C279.2, C280.2, C281.2, C282.2, C283.1, C286.2, C287.2, C288.2, D63.C, D64.3, J61.SLEEVE, J62.GND, J63.2, J64.4, R380.1, R382.1, R383.1, R384.1, R391.2, R392.2, R393.2, R394.2, R395.2, R396.2, R400.2, U31.6, U31.8, U31.18, U31.31, U31.38, U31.41, U31.42, U31.48, U32.4
GND16: C289.1, C290.1, C291.2, C292.2, C293.2, C294.2, C295.2, C296.2, C297.2, C298.2, C299.2, C300.2, C301.1, C304.2, C305.2, C306.2, D67.C, D68.3, J65.SLEEVE, J66.GND, J67.2, J68.4, R405.1, R407.1, R408.1, R409.1, R416.2, R417.2, R418.2, R419.2, R420.2, R421.2, R425.2, U33.6, U33.8, U33.18, U33.31, U33.38, U33.41, U33.42, U33.48, U34.4
GND17: C307.1, C308.1, C309.2, C310.2, C311.2, C312.2, C313.2, C314.2, C315.2, C316.2, C317.2, C318.2, C319.1, C322.2, C323.2, C324.2, D71.C, D72.3, J69.SLEEVE, J70.GND, J71.2, J72.4, R430.1, R432.1, R433.1, R434.1, R441.2, R442.2, R443.2, R444.2, R445.2, R446.2, R450.2, U35.6, U35.8, U35.18, U35.31, U35.38, U35.41, U35.42, U35.48, U36.4
GND18: C325.1, C326.1, C327.2, C328.2, C329.2, C330.2, C331.2, C332.2, C333.2, C334.2, C335.2, C336.2, C337.1, C340.2, C341.2, C342.2, D75.C, D76.3, J73.SLEEVE, J74.GND, J75.2, J76.4, R455.1, R457.1, R458.1, R459.1, R466.2, R467.2, R468.2, R469.2, R470.2, R471.2, R475.2, U37.6, U37.8, U37.18, U37.31, U37.38, U37.41, U37.42, U37.48, U38.4
GND19: C343.1, C344.1, C345.2, C346.2, C347.2, C348.2, C349.2, C350.2, C351.2, C352.2, C353.2, C354.2, C355.1, C358.2, C359.2, C360.2, D79.C, D80.3, J77.SLEEVE, J78.GND, J79.2, J80.4, R480.1, R482.1, R483.1, R484.1, R491.2, R492.2, R493.2, R494.2, R495.2, R496.2, R500.2, U39.6, U39.8, U39.18, U39.31, U39.38, U39.41, U39.42, U39.48, U40.4
IO_00: J3.3, R19.1, U2.2
IO_01: J3.4, R20.1, U2.3
IO_02: J3.5, R21.1, U2.4
IO_03: J3.6, R22.1, U2.5
IO_04: J3.7, R23.1, U2.9
IO_05: J3.8, R24.1, U2.10
IO_06: R26.1, U2.11
IO_07: R13.1, U2.12
IO_08: J7.8, R46.1, U1.10
IO_09: J7.3, R41.1, U1.2
IO_10: J7.4, R42.1, U1.3
IO_11: J7.6, R44.1, U1.5
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

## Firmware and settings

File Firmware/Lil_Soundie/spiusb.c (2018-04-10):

/// \file spiusb.c Winbond 25X16 SPI flash/USB/Vorbis player demo project
/*

   Copyright 2008 VLSI Solution, Tampere, Finland. Absolutely no warranty.


   S P I   F L A S H   U S B   D R I V E  +  P L A Y E R   E X A M P L E
   ---------------------------------------------------------------------

   This example code uses the 18 kilobytes of mallocAreaY to implement
   a disk read/write cache and work area that is capable of erasing and
   programming an SPI flash chip such as the Winbond 25X16 in 4 kilobyte
   chunks when the VS1000B is connected to USB. Tested with Windows XP.

Note: The SPI flash is quite slow to write to (about the speed of
a floppy disk). Writing small files (a few kilobytes) is fast due
to the cache system. Large files may cause occasional timeouts with
slow flash chips.

Requirements: An SPI flash eeprom with 4 kilobyte erasable blocks.

Tested with VS1000B, Winbond 25X16 and Windows XP Professional.
Measured performance: 1 megabyte file was written in 55 seconds when
the eeprom was blank (no need to erase). When writing over already
written data, writing the same file took 1 minute 35 seconds.

Builds with vskit133 build script (BUILD SPIUSB)
eeprom.img can be then prommed to the eeprom for bootable system.
Then you can use your development board to make a master EEPROM image,
which you can copy to the production units using an eeprommer.

At first connect the USB disk is unformatted.
Suggestion: use "Quick Format" when formatting the disk with WinXP.


FAT12 Subdirectory ("Folder") Limitations
-----------------------------------------
This version of code does not handle FAT12 subdirectories. Windows
forces all disks smaller than 16 megabytes to be FAT12. VLSI has
a binary fix for the problem, but it is not distributable in C code form.
You can request the FAT12 fix library from support@vlsi.fi for deployment
of your product.

The pre-compiled example image (vs1000b_25X16_spiflash_usb_player.img)
on VLSI web page has the fix installed.

- Description of FAT12 subdirectory limitation:
FAT12 subdirectory handling is omitted by choice from the VS1000B ROM,
because it requires special handling and FAT12 was not seen to be
necessary for player applications. This has the effect of hanging up the
ROM code when the ROM code looks for Ogg Vorbis files to be played,
if the disk has a FAT12 subdirectory. If your code does not try to play
Vorbis files, then there is no problem.

Our binary patch allows the ROM functions to successfully skip the
subdirectories without crashing. Vorbis files are playable from
the root directory.


*/



// The number of 512-byte blocks totally available in the SPI Flash chip
#define CHIP_TOTAL_BLOCKS 1024 /* 1024 * 512 bytes = 5Kb (ADESTO AT25SF041) */

// Set aside some blocks for VS1000 boot code (and optional parameter data)
#define RESERVED_BLOCKS 32

#define LOGICAL_DISK_BLOCKS  (CHIP_TOTAL_BLOCKS-RESERVED_BLOCKS)

#define PRINT_VS3EMU_DEBUG_MESSAGES 0

#define SPI_CLOCK_DIVIDER 2

// number of 512-blocks in RAM cache (MUST BE 16 DO NOT ALTER! I MEAN IT!)
#define CACHE_BLOCKS 16

// Position of workspace in Y ram, do not change.
#define WORKSPACE (mallocAreaY + 6144)

// storing the disk data inverted is optimal for the system.
// storing the disk data uninverted (as is) makes it easier to debug the SPI image
#define USE_INVERTED_DISK_DATA 1

#include <stdio.h>  // Standard io
#include <stdlib.h> // VS_DSP Standard Library
#include <vs1000.h> // VS1000B register definitions
#include <vectors.h>  // VS1000B vectors (interrupts and services)
#include <minifat.h>  // Read Only Fat Filesystem
#include <mapper.h> // Logical Disk
#include <string.h> // memcpy etc
#include <player.h> // VS1000B default ROM player
#include <audio.h>  // DAC output
#include <codec.h>  // CODEC interface
#include <vsNand.h>
#include <mappertiny.h>
#include <usb.h>

#include "system.h"
#include "gpioctrl.h"

#if USE_WAV
#define PLAYFILE PlayWavOrOggFile
#else
#define PLAYFILE PlayCurrentFile
#endif

#define DT_LANGUAGES 0
#define DT_VENDOR 1
#define DT_MODEL 2
#define DT_SERIAL 3
#define DT_DEVICE 4
#define DT_CONFIGURATION 5

#define VENDOR_NAME_LENGTH 7
const u_int16 myVendorNameStr[] = {
  ((VENDOR_NAME_LENGTH * 2 + 2) << 8) | 0x03,
  'V' << 8, 'l' << 8, 's' << 8, 'i' << 8, 'F' << 8, 'i' << 8, 'n' << 8
};

#define MODEL_NAME_LENGTH 8
const u_int16 myModelNameStr[] = {
  ((MODEL_NAME_LENGTH * 2 + 2) << 8) | 0x03,
  'S' << 8, 'P' << 8, 'I' << 8, 'S' << 8, 't' << 8, 'o' << 8, 'r' << 8, 'e' << 8
};

#define SERIAL_NUMBER_LENGTH 12
u_int16 mySerialNumberStr[] = {
  ((SERIAL_NUMBER_LENGTH * 2 + 2) << 8) | 0x03,
  '0' << 8, // You should put your own serial number here
  '0' << 8,
  '0' << 8,
  '0' << 8,
  '0' << 8,
  '0' << 8,
  '0' << 8,
  '0' << 8,
  '0' << 8,
  '0' << 8,
  '0' << 8,
  '1' << 8, // Serial number should be unique for each unit
};

// This is the new Device Descriptor. See the USB specification!
const u_int16 myDeviceDescriptor[] = "\p" "\x12"  // Length
  "\x01"  // Type (Device Descriptor)
  "\x10"  // LO(bcd USB Specification version) (.10)
  "\x01"  // HI(bcd USB Specification version) (1.)
  "\x00"  // Device Class (will be specified in configuration descriptor)
  "\x00"  // Device Subclass
  "\x00"  // Device Protocol
  "\x40"  // Endpoint 0 size (64 bytes)
  "\xfb"  // LO(Vendor ID) (0x19fb=VLSI Solution Oy)
  "\x19"  // HI(Vendor ID)
  "\xe0"  // LO(Product ID) (0xeee0 - 0xeeef : VLSI Customer Testing)
  "\xee"  // HI(Product ID) (customers can request an ID from VLSI)
  "\x00"  // LO(Release Number)
  "\x00"  // HI(Release Number)
  "\x01"  // Index of Vendor (manufacturer) name string
  "\x02"  // Index of Product (model) name string (most shown by windows)
  "\x03"  // Index of serial number string
  "\x01"  // Number of configurations (1)
  ;

// When a USB setup packet is received, install our descriptors
// and then proceed to the ROM function RealDecodeSetupPacket.
void RealInitUSBDescriptors (u_int16 initDescriptors);
void MyInitUSBDescriptors (u_int16 initDescriptors)
{
  RealInitUSBDescriptors (1); // ROM set descriptors for mass storage
  USB.descriptorTable[DT_VENDOR] = myVendorNameStr;
  USB.descriptorTable[DT_MODEL] = myModelNameStr;
  USB.descriptorTable[DT_SERIAL] = mySerialNumberStr;
  USB.descriptorTable[DT_DEVICE] = myDeviceDescriptor;
  // USB.descriptorTable[DT_CONFIGURATION] = myConfigurationDescriptor;
  // USB.configurationDescriptorSize = CONFIG_DESC_SIZE;
}

#if 0
// this can be helpful in making a serial number
const u_int16 bHexChar16[] = {  // swapped Unicode hex characters
  0x3000, 0x3100, 0x3200, 0x3300, 0x3400, 0x3500, 0x3600, 0x3700,
  0x3800, 0x3900, 0x4100, 0x4200, 0x4300, 0x4400, 0x4400, 0x4500
};

My void MakeSerialNumber (u_int32 newSerialNumber)
{
  u_int16 i;
  u_int32 mySerialNumber = newSerialNumber;
  // Put unique serial number to serial number descriptor
  for (i = 5; i < 13; i++)
  {
    mySerialNumberStr[i] = bHexChar16[mySerialNumber >> 28];
    mySerialNumber <<= 4;
  }
}
#endif

extern struct FsNandPhys fsNandPhys;
extern struct FsPhysical *ph;
extern struct FsMapper *map;
extern struct Codec *cod;
extern struct CodecServices cs;
extern u_int16 codecVorbis[];

/* cache info */
u_int16 blockPresent;
u_int16 blockAddress[CACHE_BLOCKS];
s_int16 lastFoundBlock = -1;
u_int16 shouldFlush = 0;

enum CodecError PlayWavOrOggFile (void);

// Do we want to get debug screen output? It's available if the code
// is loaded with vs3emu (build script) with RS-232 cable.

#if PRINT_VS3EMU_DEBUG_MESSAGES
__y const char hex[] = "0123456789abcdef";
void puthex (u_int16 a)
{
  char tmp[6];
  tmp[0] = hex[(a >> 12) & 15];
  tmp[1] = hex[(a >> 8) & 15];
  tmp[2] = hex[(a >> 4) & 15];
  tmp[3] = hex[(a >> 0) & 15];
  tmp[4] = ' ';
  tmp[5] = '\0';
  fputs (tmp, stdout);
}

void PrintCache ()
{
  register u_int16 i;
  for (i = 0; i < CACHE_BLOCKS; i++)
  {
    if (blockPresent & 1 << i)
    {
      puthex (blockAddress[i]);
    }
    else
    {
      fputs ("- ", stdout);
    }
  }
  puts ("=cache");
}

#define do__not__puts(x) puts(x)
#define do__not__puthex(x) puthex(x)
#else
#define do__not__puts(a)
#define do__not__puthex(a)
#define PrintCache()
#endif

#define SPI_EEPROM_COMMAND_WRITE_ENABLE  0x06
#define SPI_EEPROM_COMMAND_WRITE_DISABLE  0x04
#define SPI_EEPROM_COMMAND_READ_STATUS_REGISTER  0x05
#define SPI_EEPROM_COMMAND_WRITE_STATUS_REGISTER  0x01
#define SPI_EEPROM_COMMAND_READ  0x03
#define SPI_EEPROM_COMMAND_WRITE 0x02
#define SPI_EEPROM_COMMAND_CLEAR_ERROR_FLAGS 0x30
#define SPI_EEPROM_COMMAND_ERASE_BLOCK 0xD8
#define SPI_EEPROM_COMMAND_ERASE_SECTOR 0x20
#define SPI_EEPROM_COMMAND_ERASE_CHIP 0xC7

//macro to set SPI to MASTER; 8BIT; FSYNC Idle => xCS high
#define SPI_MASTER_8BIT_CSHI   PERIP(SPI0_CONFIG) = \
                                                    SPI_CF_MASTER | SPI_CF_DLEN8 | SPI_CF_FSIDLE1

//macro to set SPI to MASTER; 8BIT; FSYNC not Idle => xCS low
#define SPI_MASTER_8BIT_CSLO   PERIP(SPI0_CONFIG) = \
                                                    SPI_CF_MASTER | SPI_CF_DLEN8 | SPI_CF_FSIDLE0

//macro to set SPI to MASTER; 16BIT; FSYNC not Idle => xCS low
#define SPI_MASTER_16BIT_CSLO  PERIP(SPI0_CONFIG) = \
                                                    SPI_CF_MASTER | SPI_CF_DLEN16 | SPI_CF_FSIDLE0

void SingleCycleCommand (u_int16 cmd)
{
  SPI_MASTER_8BIT_CSHI;
  SPI_MASTER_8BIT_CSLO;
  SpiSendReceive (cmd);
  SPI_MASTER_8BIT_CSHI;
}

/// Wait for not_busy (status[0] = 0) and return status
u_int16 SpiWaitStatus (void)
{
  u_int16 status;
  SPI_MASTER_8BIT_CSHI;
  SPI_MASTER_8BIT_CSLO;
  SpiSendReceive (SPI_EEPROM_COMMAND_READ_STATUS_REGISTER);
  do
  {
    status = SpiSendReceive (0);
    if (PERIP (USB_STATUS) & USB_STF_BUS_RESET)
    {
      USBHandler ();
      SPI_MASTER_8BIT_CSHI;
      return -1;  /* USB HAS BEEN RESET */
    }
  }
  while (status & 0x01);
  ; // Wait until chip is ready or return -1 if USB bus reset

  SPI_MASTER_8BIT_CSHI;

  return status;
}


void EeUnprotect ()
{
  SingleCycleCommand (SPI_EEPROM_COMMAND_WRITE_ENABLE);
  SPI_MASTER_8BIT_CSLO;
  SpiSendReceive (SPI_EEPROM_COMMAND_WRITE_STATUS_REGISTER);
  SpiSendReceive (0x02);  // Sector Protections Off
  SPI_MASTER_8BIT_CSHI;
  SpiWaitStatus ();
  SingleCycleCommand (SPI_EEPROM_COMMAND_WRITE_ENABLE);
}

void EePutReadBlockAddress (register u_int16 blockn)
{
  SPI_MASTER_8BIT_CSLO;
  SpiSendReceive (SPI_EEPROM_COMMAND_READ);
  SpiSendReceive (blockn >> 7); // Address[23:16] = blockn[14:7]
  SpiSendReceive ((blockn << 1) & 0xff);  // Address[15:8] = blockn[6:0]0
  SpiSendReceive (0); // Address[7:0] = 00000000
  SPI_MASTER_16BIT_CSLO;
}

// Check is a 4K block completely blank
u_int16 EeIsBlockErased (u_int16 blockn)
{
  SpiWaitStatus ();
  EePutReadBlockAddress (blockn);
  {
    register u_int16 n;
    for (n = 0; n < 2048; n++)
    {
      if (SpiSendReceive (0) != 0xffff)
      {
        SPI_MASTER_8BIT_CSHI;
        return 0;
      }
    }
    SPI_MASTER_8BIT_CSHI;
    return 1;
  }
}

s_int16 EeProgram4K (u_int16 blockn, __y u_int16 * dptr)
{

  PERIP (USB_EP_ST3) |= (0x0001); // Force NAK on EP3 (perhaps not needed?)

  do__not__puthex (blockn);
  do__not__puts ("= write 4K");

  if (!EeIsBlockErased (blockn))
  { // don't erase if not needed
    // Erase 4K sector
    SingleCycleCommand (SPI_EEPROM_COMMAND_WRITE_ENABLE);
    SingleCycleCommand (SPI_EEPROM_COMMAND_CLEAR_ERROR_FLAGS);
    EeUnprotect ();
    SPI_MASTER_8BIT_CSLO;
    SpiSendReceive (SPI_EEPROM_COMMAND_ERASE_SECTOR);
    SpiSendReceive (blockn >> 7); // Address[23:16] = blockn[14:7]
    SpiSendReceive ((blockn << 1) & 0xff);  // Address[15:8] = blockn[6:0]0
    SpiSendReceive (0); // Address[7:0] = 00000000
    SPI_MASTER_8BIT_CSHI;
  }

  if (SpiWaitStatus () == -1)
    return -1;  /* USB HAS BEEN RESET */
  // Write 8 512-byte sectors
  {
    u_int16 i;
    for (i = 0; i < 8; i++)
    {

      // Put first page (256 bytes) of sector.
      EeUnprotect ();
      SPI_MASTER_8BIT_CSLO;
      SpiSendReceive (SPI_EEPROM_COMMAND_WRITE);
      SpiSendReceive (blockn >> 7); // Address[23:16] = blockn[14:7]
      SpiSendReceive ((blockn << 1) & 0xff);  // Address[15:8] = blockn[6:0]0
      SpiSendReceive (0); // Address[7:0] = 00000000
      SPI_MASTER_16BIT_CSLO;
      {
        u_int16 n;
        for (n = 0; n < 128; n++)
        {
#if USE_INVERTED_DISK_DATA
          SpiSendReceive (~(*dptr++));
#else
          SpiSendReceive ((*dptr++));
#endif
        }
      }
      SPI_MASTER_8BIT_CSHI;
      if (SpiWaitStatus () == -1)
        return -1;  /* USB HAS BEEN RESET */

      // Put second page (256 bytes) of sector.
      EeUnprotect ();
      SPI_MASTER_8BIT_CSLO;
      SpiSendReceive (SPI_EEPROM_COMMAND_WRITE);
      SpiSendReceive (blockn >> 7); // Address[23:16] = blockn[14:7]
      SpiSendReceive (((blockn << 1) + 1) & 0xff);  // Address[15:8] =
      // blockn[6:0]1
      SpiSendReceive (0); // Address[7:0] = 00000000
      SPI_MASTER_16BIT_CSLO;
      {
        u_int16 n;
        for (n = 0; n < 128; n++)
        {
#if USE_INVERTED_DISK_DATA
          SpiSendReceive (~(*dptr++));
#else
          SpiSendReceive ((*dptr++));
#endif
        }
      }
      SPI_MASTER_8BIT_CSHI;
      if (SpiWaitStatus () == -1)
        return -1;  /* USB HAS BEEN RESET */
      blockn++;
    }
  }
  do__not__puts ("written");

  PERIP (USB_EP_ST3) &= ~(0x0001);  // Un-Force NAK on EP3
  return 0;

}



// Block Read for SPI EEPROMS with 24-bit address e.g. up to 16MB
u_int16 EeReadBlock (u_int16 blockn, u_int16 * dptr)
{
  SpiWaitStatus ();

  EePutReadBlockAddress (blockn);
  {
    int n;
    for (n = 0; n < 256; n++)
    {
#if USE_INVERTED_DISK_DATA
      *dptr++ = ~SpiSendReceive (0);
#else
      *dptr++ = SpiSendReceive (0);
#endif
    }
  }
  SPI_MASTER_8BIT_CSHI;
  return 0;
}

// Returns 1 if block differs from data, 0 if block is the same
u_int16 EeCompareBlock (u_int16 blockn, u_int16 * dptr)
{
  SpiWaitStatus ();

  EePutReadBlockAddress (blockn);
  {
    int n;
    for (n = 0; n < 256; n++)
    {

#if USE_INVERTED_DISK_DATA
      if ((*dptr++) != (~SpiSendReceive (0)))
#else
      if ((*dptr++) != (SpiSendReceive (0)))
#endif
      {
        SPI_MASTER_8BIT_CSHI;
        return 1;
      }
    }
  }
  SPI_MASTER_8BIT_CSHI;
  return 0;
}

u_int16 EeRead4KSectorYToWorkspace (u_int16 blockn)
{
  register __y u_int16 *dptr;
  dptr = WORKSPACE;
  SpiWaitStatus ();
  blockn &= 0xfff8; // always point to first block of 4k sector


  EePutReadBlockAddress (blockn);
  {
    int n;
    for (n = 0; n < 2048; n++)
    {
#if USE_INVERTED_DISK_DATA
      *dptr++ = ~SpiSendReceive (0);
#else
      *dptr++ = SpiSendReceive (0);
#endif
    }
  }
  SPI_MASTER_8BIT_CSHI;
  return 0;
}

void InitSpi (u_int16 clockDivider)
{
  SPI_MASTER_8BIT_CSHI;
  PERIP (SPI0_FSYNC) = 0;
  PERIP (SPI0_CLKCONFIG) = SPI_CC_CLKDIV * (clockDivider - 1);
  PERIP (GPIO1_MODE) |= 0x1f; /* enable SPI pins */
}


__y u_int16 *FindCachedBlock (u_int16 blockNumber)
{
  register int i;
  lastFoundBlock = -1;
  for (i = 0; i < CACHE_BLOCKS; i++)
  {
    if ((blockPresent & 1 /* was L */  << i)
        && (blockAddress[i] == blockNumber))
    {
      lastFoundBlock = i;
      return mallocAreaY + 256 * i;
    }
  }
  return NULL;
}


u_int16 WriteContinuous4K ()
{
  u_int16 i, k;
  for (i = 0; i < CACHE_BLOCKS - 7; i++)
  { // for all cached blocks...
    if ((blockPresent & 1 /* was L */  << i)
        && ((blockAddress[i] & 0x0007) == 0))
    {
      // cached block i contains first 512 of 4K
      for (k = 1; k < 8; k++)
      {
        if (blockAddress[i + k] != blockAddress[i] + k)
          goto ohi;
      }
      do__not__puthex (blockAddress[i]);
      do__not__puts (" starts continuous 4K ");

      if (-1 != EeProgram4K (blockAddress[i], mallocAreaY + 256 * i))
      {
        for (k = 0; k < 8; k++)
        {
          blockPresent &= ~(1 /* was L */  << (i + k));
        }
      }
      else
      {
        return 0; /* USB HAS BEEN RESET */
      }
      return 1;
    }
  ohi:
    {
    }
  }
  return 0;
}

__y u_int16 *GetEmptyBlock (u_int16 blockNumber)
{
  register int i;
  for (i = 0; i < CACHE_BLOCKS; i++)
  {
    if (!(blockPresent & 1 /* was L */  << i))
    {
      blockPresent |= 1 /* was L */  << i;
      blockAddress[i] = blockNumber;
      return mallocAreaY + 256 * i;
    }
  }
  // do__not__puts("cannot allocate empty block");
  return NULL;
}



struct FsMapper *FsMapSpiFlashCreate (struct FsPhysical *physical,
                                      u_int16 cacheSize);
s_int16 FsMapSpiFlashRead (struct FsMapper *map, u_int32 firstBlock,
                           u_int16 blocks, u_int16 * data);
s_int16 FsMapSpiFlashWrite (struct FsMapper *map, u_int32 firstBlock,
                            u_int16 blocks, u_int16 * data);
s_int16 FsMapSpiFlashFlush (struct FsMapper *map, u_int16 hard);


const struct FsMapper spiFlashMapper = {
  0x010c, /* version */
  256,  /* blocksize */
  LOGICAL_DISK_BLOCKS,  /* blocks */
  0,  /* cacheBlocks */
  FsMapSpiFlashCreate,
  FsMapFlNullOk,  // RamMapperDelete,
  FsMapSpiFlashRead,
  FsMapSpiFlashWrite,
  NULL, // FsMapFlNullOk,//RamMapperFree,
  FsMapSpiFlashFlush, // RamMapperFlush,
  NULL  /* no physical */
};

struct FsMapper *FsMapSpiFlashCreate (struct FsPhysical *physical,
                                      u_int16 cacheSize)
{

  do__not__puts ("CREATE");
  InitSpi (SPI_CLOCK_DIVIDER);
  blockPresent = 0;
  shouldFlush = 0;
  return &spiFlashMapper;
}



s_int16 FsMapSpiFlashRead (struct FsMapper * map, u_int32 firstBlock,
                           u_int16 blocks, u_int16 * data)
{
  register s_int16 bl = 0;

  if (shouldFlush)
    return 0;
  firstBlock += RESERVED_BLOCKS;

  while (bl < blocks)
  {
    __y u_int16 *source = FindCachedBlock (firstBlock);
#if 0
    do__not__puthex (firstBlock);
    do__not__puthex ((u_int16) source);
    do__not__puts ("=rd_lba, addr");
#endif
    if (source)
    {
      memcpyYX (data, source, 256);
    }
    else
    {
      EeReadBlock (firstBlock, data);
      // memset(data, 0, 256);
    }
    data += 256;
    firstBlock++;
    bl++;
  }
  return bl;
}
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
void main (void)
{

  do__not__puts ("Hello.");

  InitAudio ();
  GPIOInit ();

  PERIP (INT_ENABLEL) = INTF_RX | INTF_TIM0;
  PERIP (INT_ENABLEH) = INTF_DAC;

  PERIP (SCI_STATUS) &= ~SCISTF_USB_PULLUP_ENA;
  PERIP (USB_CONFIG) = 0x8000U;

  PERIP (GPIO1_ODATA) |= LED1 | LED2;
  PERIP (GPIO1_DDR) |= LED1 | LED2;
  PERIP (GPIO1_MODE) &= ~(LED1 | LED2);

  player.volumeOffset = -24;
  player.pauseOn = 0;

  keyOld = KEY_POWER;
  keyOldTime = -32767;

  SetHookFunction ((u_int16) OpenFile, Fat12OpenFile);

  // Set the GPIO hook to look at GPIO pins
  SetHookFunction ((u_int16) IdleHook, GPIOCtrlIdleHook);

  // Use our SPI flash mapper as logical disk
  map = FsMapSpiFlashCreate (NULL, 0);
  player.volume = 0;
  PlayerVolume ();

  // Use custom main loop to take over total control of chip
  while (1)
  {
    // When USB is attached, go to mass storage handler
    if (USBIsAttached ())
    {
      do__not__puts ("MassStorage");
      MyMassStorage ();
      do__not__puts ("From MassStorage");
    }
    // puts("Test");

    // Try to use a FAT filesystem on logical disk
    if (InitFileSystem () == 0)
    {
      minifatInfo.supportedSuffixes = defSupportedFiles;

      // Look for playable files
      player.totalFiles = OpenFile (0xffffU);
      player.currentFile = 0xffffU;
      do__not__puts ("Total Files");
      do__not__puthex (player.totalFiles);
      do__not__puts ("");
      if (player.totalFiles == 0)
      {
        goto noFSnorFiles;
      }

      // Playable file(s) found. Play.
      player.nextStep = 1;
      player.nextFile = 0;
      while (1)
      {
        // Check the current pin settings
        GPIOCtrlIdleHook ();

        // If current file is empty play silence
        while (player.currentFile == 0xffffU)
        {
          memset (tmpBuf, 0, sizeof (tmpBuf));
          AudioOutputSamples (tmpBuf, sizeof (tmpBuf) / 2);
          if (USBIsAttached ())
          {
            break;
          }
        }

        if (player.currentFile < player.totalFiles && OpenFile (player.currentFile) < 0)
        {
          player.ffCount = 0;
          cs.cancel = 0;
          cs.goTo = -1;
          cs.fileSize = cs.fileLeft = minifatInfo.fileSize;
          cs.fastForward = 1;
          {
            register s_int16 oldStep = player.nextStep;
            register s_int16 ret;

            do__not__puts ("Current playing file");
            do__not__puthex (player.currentFile);
            do__not__puts ("");
            ret = PLAYFILE ();  // Decode and Play.
            do__not__puts ("Player return value");
            do__not__puthex (ret);
            do__not__puts ("");
            // See separate examples about keyboard handling.
          }
        }
        else
        {
          player.currentFile = 0xffffU;
          continue;
        }

        // If USB is attached, return to main loop
        if (USBIsAttached ())
        {
          break;
        }
      }
    }
    else
    {
    noFSnorFiles:
      LoadCheck (&cs, 32);
      memset (tmpBuf, 0, sizeof (tmpBuf));  /* silence */
      AudioOutputSamples (tmpBuf, sizeof (tmpBuf) / 2); /* silence */
    }
  }
}

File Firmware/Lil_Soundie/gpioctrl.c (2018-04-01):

#include "system.h"

#include <stdio.h>  // Standard io
#include <stdlib.h> // VS_DSP Standard Library
#include <vs1000.h> // VS1000B register definitions
#include <vectors.h>  // VS1000B vectors (interrupts and services)
#include <minifat.h>  // Read Only Fat Filesystem
#include <mapper.h> // Logical Disk
#include <string.h> // memcpy etc
#include <player.h> // VS1000B default ROM player
#include <audio.h>  // DAC output
#include <codec.h>  // CODEC interface
#include <vsNand.h>
#include <mappertiny.h>
#include <usb.h>

#include <dev1000.h>

#include "gpioctrl.h"

extern struct CodecServices cs;
void puthex (u_int16 a);
/*
   We currently allow two GPIO controls:
   1) GPIO_MASK for binary-encoded file number, all-zero means idle.
   The playing file is changed when the value changes to another non-zero
   value while a file is playing. The file is repeated if the number
   remains at the GPIO pins after the playback has finished.

   The number of bits used can be configured from 1 to 8 (GPIO0[0:7])
   for 255 files when SD card is used, and from 1 to 13 (GPIO0[0:12])
   for 8191 files when SD card is not used.

   2) GPIO_PRIORITIES for one GPIO per file with priorities.
   Lower number GPIO pin number has priority over a higher number GPIO pin.
   A higher number GPIO pin does not interrupt the playing of a current
   file, even if the lower number GPIO pin is no longer set.
   The file is repeated if a file is selected by the GPIO pins after the
   playback has finished.

   The number of GPIO pins used can be configured from 1 to 8 (GPIO0[0:7])
   when SD card is used, and from 1 to 13 (GPIO0[0:12]) when SD card is
   not used.

   Playing indicator:
   -
   See system.h for GPIO_NUMBERED_FILES definition
   */

#define GPIO_MASK       0x001f  // Sel. file w/ GPIO0 pins in the mask
//#define GPIO_INVERTED   //default state is HIGH, buttons bring low
//#define GPIO_PRIORITIES 0x04ff // Sel. file w/ GPIO0 pins, lower has priority

//#define GPIO0_READY_INDICATOR    GPIO0_CLE
//#define GPIO0_PLAYING_INDICATOR  GPIO0_CLE /*CLE=GPIO0_12*/
/*Note: CLE is a bad choice, because it does not come to an audio module pin.*/
#define GPIO0_PLAYING_INDICATOR  (1<<6) // GPIO0_CLE /*CLE=GPIO0_12*/


#if defined(GPIO_MASK) && defined(GPIO_PRIORITIES)
err 'Both GPIO_MASK and GPIO_PRIORITIES can not be defined at the same time'
#endif
void GPIOCtrlIdleHook (void)
{

  if (uiTrigger)
  {
    uiTrigger = 0;

    /* 
     * If you want the default firmware key-controls, use KeyScan(); */

#ifdef GPIO0_PLAYING_INDICATOR
    /* We do it this way so that the logic can be in this file. */
    if (player.currentFile != -1)
    {
      /* high = playing */
      PERIP (GPIO0_SET_MASK) = GPIO0_PLAYING_INDICATOR;
    }
    else
    {
      /* low = waiting for GPIO */
      PERIP (GPIO0_CLEAR_MASK) = GPIO0_PLAYING_INDICATOR;
    }
#endif

    /* TURN GPIO into GPIO mode. */
#ifdef GPIO_MASK
    /* Direct selection through GPIO pins. */
    {
      register s_int16 mask;
#ifdef GPIO_INVERTED
      /* default state is high, button pulls low to GND */
      PERIP (GPIO0_SET_MASK) = GPIO_MASK | GPIO0_PULLUPS;
      PERIP (GPIO0_DDR) |= GPIO_MASK; // Drive to 1
      for (mask = 0; mask < 10000; mask++)
        USEX (0);
      PERIP (GPIO0_DDR) &= ~GPIO_MASK;  // To inputs
      for (mask = 0; mask < 10000; mask++)
        USEX (0);
      mask = ((PERIP (GPIO0_IDATA) ^ GPIO0_PULLUPS) & GPIO_MASK) ^ GPIO_MASK;
#else
      /* default state is low, button pulls high to IOVDD */
      PERIP (GPIO0_CLEAR_MASK) = GPIO_MASK;
      PERIP (GPIO0_SET_MASK) = GPIO_MASK & GPIO0_PULLUPS;
      PERIP (GPIO0_DDR) |= GPIO_MASK; // Drive to 0
      for (mask = 0; mask < 10000; mask++)
        USEX (0);
      PERIP (GPIO0_DDR) &= ~GPIO_MASK;  // To inputs
      for (mask = 0; mask < 10000; mask++)
        USEX (0);
      mask = (PERIP (GPIO0_IDATA) ^ GPIO0_PULLUPS) & GPIO_MASK;

#endif
      // putch(mask);

      if (mask)
      {
        player.currentFile = player.nextFile = mask - 1;
        player.pauseOn = 0;
      }
      else
      {
        player.currentFile = 0xffffU;
      }
    }
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

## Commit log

2017-12-08 Updated design: active high input pins. Cleaned up schematic and layout
    [SparkFun_Lil_Soundie_Audio_Player.brd, SparkFun_Lil_Soundie_Audio_Player.sch]
2017-12-13 Fixed trace issue on IO7
    [SparkFun_Lil_Soundie_Audio_Player.brd, SparkFun_Lil_Soundie_Audio_Player.sch]
2017-12-13 Updated per QC review
    [SparkFun_Lil_Soundie_Audio_Player.brd, SparkFun_Lil_Soundie_Audio_Player.sch]
2017-12-13 Moving LED
    [SparkFun_Lil_Soundie_Audio_Player.brd]
2018-02-11 Add switch to turn on/off WAV playback
2018-02-11 Fix bug for mounting USB
    [spiusb.c]
2018-02-11 Remove prints so promming binary works
2018-02-20 Updating Silk
    [SparkFun_Lil_Soundie_Audio_Player.brd, SparkFun_Lil_Soundie_Audio_Player.sch]
2018-02-20 Updated name
    [SparkFun_Lil_Soundie_Audio_Player.sch]
2018-02-22 Created panel v10
    [SparkFun_Lil_Soundie_Audio_Player-Panel_v10.brd]
2018-03-31 Fix device hang on non-existent file
    [spiusb.c]

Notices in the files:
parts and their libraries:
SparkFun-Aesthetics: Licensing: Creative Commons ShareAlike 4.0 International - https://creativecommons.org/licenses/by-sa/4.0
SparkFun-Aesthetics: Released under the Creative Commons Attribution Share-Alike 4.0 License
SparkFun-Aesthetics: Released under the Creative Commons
